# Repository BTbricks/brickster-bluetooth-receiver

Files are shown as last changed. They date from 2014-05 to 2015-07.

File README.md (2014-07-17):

# BricksTer &ndash; Bluetooth Receiver

BricksTer Bluetooth Receiver top side&nbsp;&nbsp;&nbsp;BricksTer Bluetooth Receiver bottom side

The BricksTer Bluetooth Receiver lets you wirelessly control your LEGO creations from a smart phone, tablet, or PC. It is compatible with the NXT programmable brick. This repository houses the Eagle CAD schematic and design files for the printed circuit board along with the firmware for the receiver.

## Getting Started

### Part List

Components can be ordered from any distributor (e.g. DigiKey, Mouser, etc).  
[Please see the Bill of Materials for the list of components.](https://github.com/BTbricks/brickster-bluetooth-receiver/blob/master/8884bt%20Remote%20Control%20Receiver/board/BOM.md)

The rev. 2 board can be purchased from OSH Park.  
[Click here to view the OSH Park project page.](https://oshpark.com/shared_projects/jNrizzs2)

### Programming the Board

Once your board is soldered, use the Arduino IDE to load the firmware onto the microcontroller.  
The IDE is available for free and can be downloaded from http://arduino.cc/main/software

#### Setting up the Arduino Environment

The microcontroller is an ATtiny84, which is not regularly supported by the Arduino IDE.  
[Please visit the Arduino support page to learn more about using Arduino with the ATtiny84.](http://playground.arduino.cc/Main/ArduinoOnOtherAtmelChips)

Download the [Attiny 44/45/84/85 files](https://github.com/damellis/attiny/archive/master.zip) and extract them to `{ARDUINO}/hardware/`, where `{ARDUINO}` represents the directory into which the Arduino IDE and supporting files have been installed. Once completed, your directory should look like this:

```
{ARDUINO}
└-hardware
  └-attiny
    ├-boards.txt
    └-variants
      ├-tiny8
      | └-pins_arduino.h
      └-tiny14
        └-pins_arduino.h
```

#### Burning the "Bootloader"

The ATtiny84 comes from the factory running on an internal 1 MHz clock. In order to run the BricksTer firmware, the ATtiny84 must be told to use its interal 8 MHz clock.

* Connect your board to your computer via the programmer
* Apply power to the power-in Power Functions wire
* Open the Arduino IDE
* Ensure you have selected the proper serial port (`Tools > Serial Port`) and can communicate with the microcontroller
* Select `Tools > Board > ATtiny84 (internal 8 Mhz clock)`
* Select `Tools > Burn Bootloader`
* Wait for the programmer to finish, the IDE should display a success message

#### Loading the Firmware

* Connect your board to your computer via the programmer
* Apply power to the power-in Power Functions wire
* Open the Arduino IDE
* Ensure you have selected the proper serial port (`Tools > Serial Port`) and can communicate with the microcontroller
* Select `Tools > Board > ATtiny84 (internal 8 Mhz clock)`
* Open the firmware file, [`brickster8884bt.ino`](https://github.com/BTbricks/brickster-bluetooth-receiver/blob/master/8884bt%20Remote%20Control%20Receiver/firmware/brickster8884bt.ino)
* Click the Upload button on the Arduino IDE (circle with a right-pointing arrow)
* Wait for the the IDE and programmer to finish, the IDE should display a success message

Note: Use of a Atmel AVRISPmk2 programmer is strongly advised. Other programmers have been known to work, but we can only provide support for the AVRISPmk2.

### File Formats

Design files are created in CadSoft Eagle PCB Design Software.  
A free version of the software can be downloaded from www.cadsoftusa.com

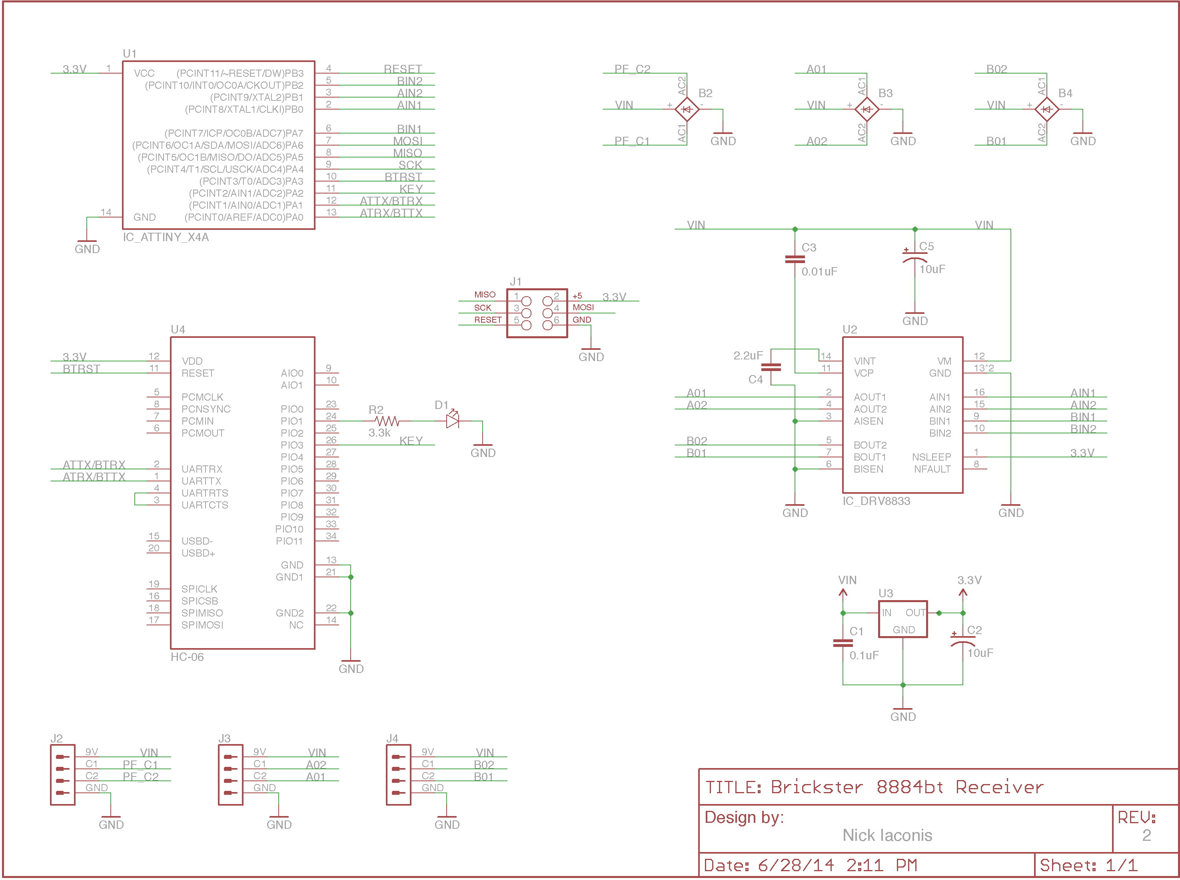
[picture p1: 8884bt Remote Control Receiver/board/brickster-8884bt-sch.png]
BricksTer Bluetooth Receiver schematic
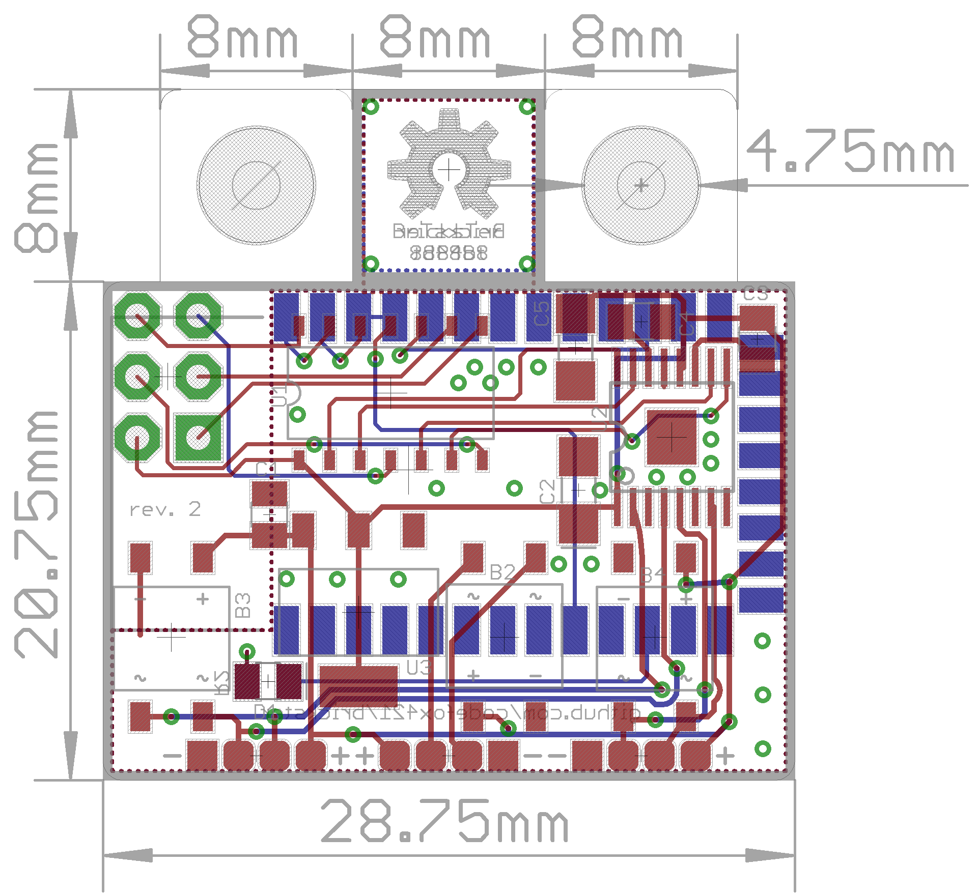
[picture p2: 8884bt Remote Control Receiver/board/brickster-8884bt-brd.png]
BricksTer Bluetooth Receiver board design
&nbsp;&nbsp;&nbsp;

## Distribution License

Where possible, this project uses the MIT license. [Please see the license file for full details.](https://github.com/BTbricks/brickster-bluetooth-receiver/blob/master/LICENSE)

## Contributing

The project is open to all issues and pull requests.  
If you have any other questions or feedback, please [contact the project maintainers](https://github.com/orgs/BTbricks/members).

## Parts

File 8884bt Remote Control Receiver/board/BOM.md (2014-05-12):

# Bill of Materials

Listed here is a complete bill of materials for assembling one bluetooth receiver.

## Example listing

+ **Identifier** Device Package (ManufacturerPartNumber) _comment_

## 8884bt Bluetooth Receiver

+ **U1** ATtiny84 SOIC14 (ATTINY84-20SSUR)
+ **U2** MotorDriver SOP16 (DRV8833PWPR)
+ **U3** Regulator3.3V SOT223 (NCP1117ST33T3G)
+ **U4** BluetoothModule SMD34 (HC-06)

+ **B2/B3/B4** BridgeRectifier MBS-2 (CDBHM240L-HF)

+ **D1** BlueLED 0805 (150080BS75000)

+ **C1** CapCer0.1uF 0805 (CC0805ZRY5V9BB104)
+ **C2/C5** CapCer10uF 1206 (CL31F106ZOHNNNE)
+ **C3** CapCer10000pF 0805 (CC0805KRX7R9BB103)
+ **C4** CapCer2.2uF 0805 (CL21F225ZOFNNNE)

+ **R2** Res3.3kOhm 0805 (RMCF0805JT3K30)

+ **J1** ProgrammerICSP N/A (N/A) _used to program the ATtiny84, use of pogo pins is advised, no external power!_
+ **J2/J3/J4** WirePF N/A ([8886](http://shop.lego.com/en-US/LEGO-Power-Functions-Extension-Wire-8886 "Power Functions Extension Wire") _or_ [8871](http://shop.lego.com/en-US/LEGO-Power-Functions-Extension-Wire-20-8871 "Power Functions Extension Wire 20"")) _octagon pads denote 9V, square pads denote GND_

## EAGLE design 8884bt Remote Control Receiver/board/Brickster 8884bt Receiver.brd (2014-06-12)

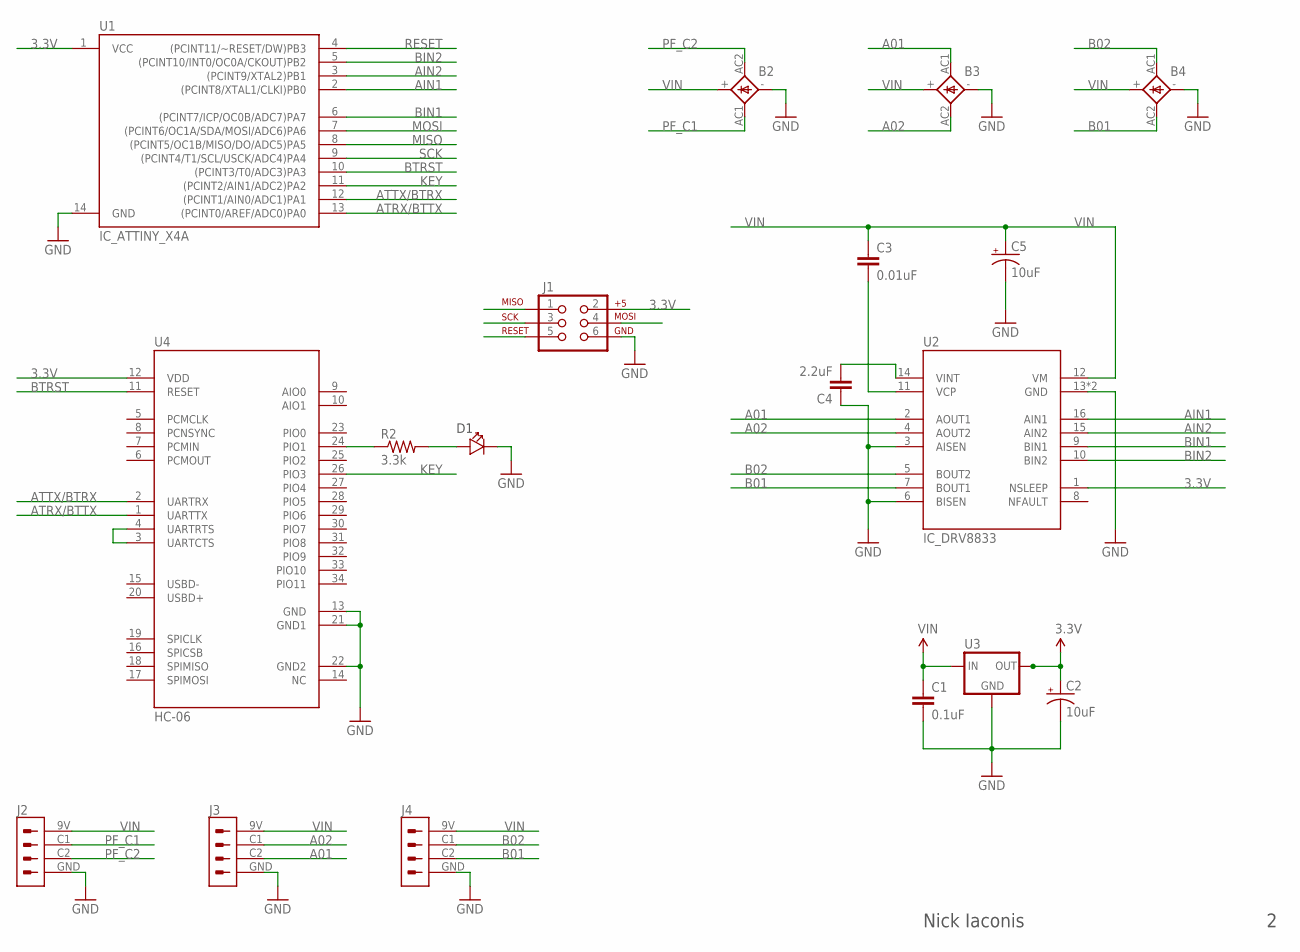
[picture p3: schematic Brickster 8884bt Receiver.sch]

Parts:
B2, B3, B4: B_CDBHM240L-HF; MBS-2
C1: 0.1uF; 0805
C2, C5: 10uF; 1206
C3: 0.01uF; 0805
C4: 2.2uF; 0805
D1: LED0805; 0805_POL
J1: AVR_SPI_PRG_6NS; 2X3-NS
J2, J3, J4: CON_PF_SMD; SMD_PF
R2: 3.3k; 0805
U1: IC_ATTINY_X4A; 14S1
U2: IC_DRV8833; PWP_R-PDSO-G16
U3: IC_RT9164A; SOT223
U4: HC-06; BLUETOOTH_SMD

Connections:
3.3V: C2.1 (+), J1.2, U1.1 (VCC), U2.1 (NSLEEP), U3.2 (OUT), U3.4, U4.12 (VDD)
A01: B3.AC1, J3.C2, U2.2 (AOUT1)
A02: B3.AC2, J3.C1, U2.4 (AOUT2)
AIN1: U1.2 ((PCINT8/XTAL1/CLKI)PB0), U2.16 (AIN1)
AIN2: U1.3 ((PCINT9/XTAL2)PB1), U2.15 (AIN2)
ATRX/BTTX: U1.13 ((PCINT0/AREF/ADC0)PA0), U4.1 (UARTTX)
ATTX/BTRX: U1.12 ((PCINT1/AIN0/ADC1)PA1), U4.2 (UARTRX)
B01: B4.AC2, J4.C2, U2.7 (BOUT1)
B02: B4.AC1, J4.C1, U2.5 (BOUT2)
BIN1: U1.6 ((PCINT7/ICP/OC0B/ADC7)PA7), U2.9 (BIN1)
BIN2: U1.5 ((PCINT10/INT0/OC0A/CKOUT)PB2), U2.10 (BIN2)
BTRST: U1.10 ((PCINT3/T0/ADC3)PA3), U4.11 (RESET)
GND: B2.-, B3.-, B4.-, C1.P$2 (2), C2.2 (-), C4.P$1 (1), C5.2 (-), D1.P$1, J1.6, J2.GND, J3.GND, J4.GND, U1.14 (GND), U2.3 (AISEN), U2.6 (BISEN), U2.13 (GND), U2.17 (GND), U3.1 (GND), U4.13 (GND), U4.21 (GND1), U4.22 (GND2)
KEY: U1.11 ((PCINT2/AIN1/ADC2)PA2), U4.26 (PIO3)
LED: R2.P$1 (1), U4.24 (PIO1)
MISO: J1.1, U1.8 ((PCINT5/OC1B/MISO/DO/ADC5)PA5)
MOSI: J1.4, U1.7 ((PCINT6/OC1A/SDA/MOSI/ADC6)PA6)
unnamed: C3.P$2 (2), U2.11 (VCP)
unnamed: C4.P$2 (2), U2.14 (VINT)
unnamed: U4.3 (UARTCTS), U4.4 (UARTRTS)
unnamed: D1.P$2, R2.P$2 (2)
PF_C1: B2.AC1, J2.C1
PF_C2: B2.AC2, J2.C2
RESET: J1.5, U1.4 ((PCINT11/~RESET/DW)PB3)
SCK: J1.3, U1.9 ((PCINT4/T1/SCL/USCK/ADC4)PA4)
VIN: B2.+, B3.+, B4.+, C1.P$1 (1), C3.P$1 (1), C5.1 (+), J2.9V, J3.9V, J4.9V, U2.12 (VM), U3.3 (IN)

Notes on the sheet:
Nick Iaconis

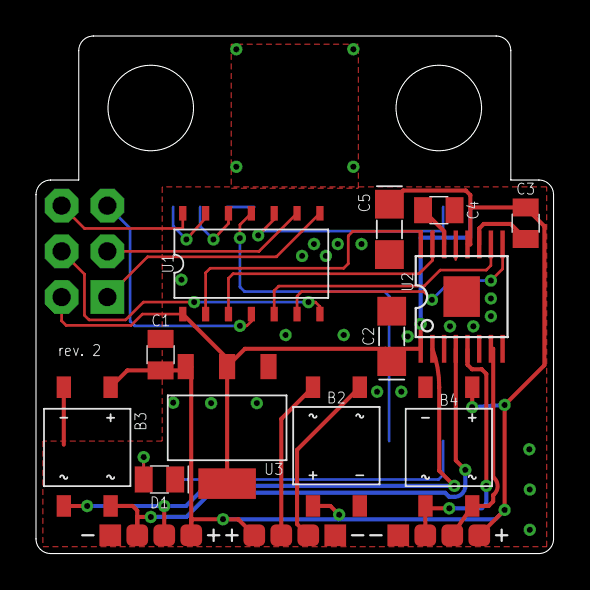
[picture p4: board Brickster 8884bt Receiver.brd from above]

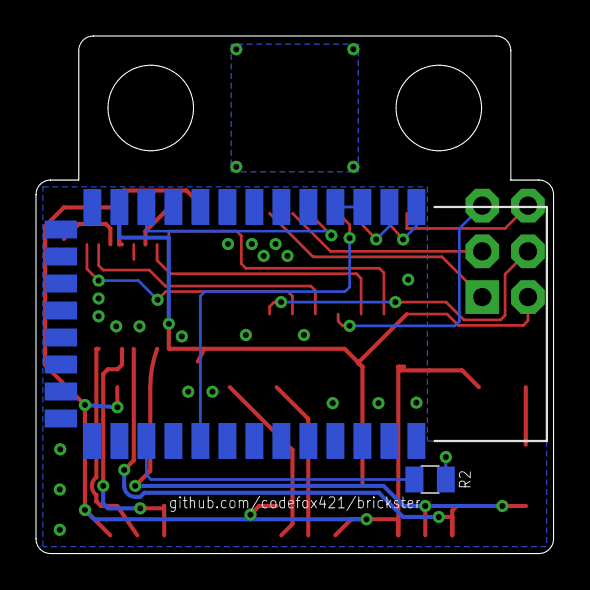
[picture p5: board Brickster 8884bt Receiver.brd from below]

Board: 2 copper layers, 28.8 x 28.8 mm, 20 parts (3 on the bottom side), 26 nets.

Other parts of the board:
LOGO1, LOGO2: OSHW-LOGOM; OSHW-LOGO-M-MASK

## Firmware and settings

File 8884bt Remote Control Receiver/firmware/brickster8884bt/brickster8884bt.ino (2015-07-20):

/*------------------------------------------------------------------------------
  The MIT License (MIT)

  Copyright (c) 2013 Nick Iaconis et al.
  
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
  THE SYSTEM IS PROVIDED "AS IS", WITHOUT WARRANTY OF ANY KIND, EXPRESS OR
  IMPLIED, INCLUDING BUT NOT LIMITED TO THE WARRANTIES OF MERCHANTABILITY,
  FITNESS FOR A PARTICULAR PURPOSE AND NONINFRINGEMENT. IN NO EVENT SHALL THE
  AUTHORS OR COPYRIGHT HOLDERS BE LIABLE FOR ANY CLAIM, DAMAGES OR OTHER
  LIABILITY, WHETHER IN AN ACTION OF CONTRACT, TORT OR OTHERWISE, ARISING FROM,
  OUT OF OR IN CONNECTION WITH THE SYSTEM OR THE USE OR OTHER DEALINGS IN THE
  SYSTEM.
------------------------------------------------------------------------------*/

/*------------------
  #### ATtiny84 ####
  ------------------
         ____       
  VCC  <|*   |> GND 
  IO10 <|    |> IO 0
  IO 9 <|    |> IO 1
  RST  <|    |> IO 2
  IO 8 <|    |> IO 3
  IO 7 <|    |> SCK 
  MOSI <|____|> MISO

  ------------------*/

/*----------------------------
  #### Swap Motor Drivers ####
  ----------------------------
  
  Regex:   ^( *)(.*tb6612fng)
  Replace: $1//$2
  
  Regex:   ^( *)//(.*drv8833)
  Replace: $1$2
  
  ----------------------------*/

#include <SoftwareSerial.h>
#define uSecCyc 870

// Motor control A
//#define mcPin1A 1 // tb6612fng
//#define mcPin2A 2 // tb6612fng
//#define pwmPinA 3 // tb6612fng
#define mcPin1A 10 // drv8833
#define mcPin2A 9 // drv8833
char pwmPinA = mcPin1A; // drv8833
#define maxA 28
char levelA = 0;
int pwmA = 0;

// Motor control B
//#define mcPin1B 0 // tb6612fng
//#define mcPin2B 8 // tb6612fng
//#define pwmPinB 7 // tb6612fng
#define mcPin1B 7 // drv8833
#define mcPin2B 8 // drv8833
char pwmPinB = mcPin1B; // drv8833
#define maxB 28
char levelB = 0;
int pwmB = 0;

// Channel A commands
#define maskA 83
#define upA 65    // A up         = A
#define downA 66  // A down       = B
#define brakeA 67 // A brake      = C
#define floatA 80 // A float      = P
#define ffwdA 81  // A full fwd   = Q
#define frevA 82  // A full rev   = R

// Channel B commands
#define maskB 108
#define upB 68    // B up         = D
#define downB 72  // B down       = H
#define brakeB 76 // B brake      = L
#define floatB 96 // B float      = `
#define ffwdB 100 // B full fwd   = d
#define frevB 104 // B full rev   = h

// Combine Channel A command with Channel B command using logical OR

// Software serial
//#define rxPin 10 // tb6612fng
//#define txPin 9 // tb6612fng
#define rxPin 0 // drv8833
#define txPin 1 // drv8833
#define baudRate 9600
SoftwareSerial softSerial(rxPin, txPin);

// Miscellanious
#define btResetPin 3
char incomingByte = 0;
char maskedByte = 0;
char serialRateLimiter = 0;
// int pwmLevels[8] = {0, 218, 326, 435, 544, 653, 761, 870};
int pwmLevels[29] = {0, 141, 168, 195, 222, 249, 276, 303, \
                      330, 357, 384, 411, 438, 465, 492, \
                      519, 546, 573, 600, 627, 654, 681, \
                      708, 735, 762, 789, 816, 843, 870};

// Function definitions
void comboMode(const char, char*, const char, const char, \
                const char, const char, const char, const char, \
                const char, const char, const char, const char);
void bitBangPwm(char, int, char, int);



/*----------------------------------------------------------------------------*/



void setup()
{
  // bluetooth control init
  pinMode(btResetPin, OUTPUT);
  digitalWrite(btResetPin, HIGH); // end Bluetooth reset (enable module)
  
  // channel A init
  pinMode(mcPin1A, OUTPUT);
  pinMode(mcPin2A, OUTPUT);
  pinMode(pwmPinA, OUTPUT);
  digitalWrite(mcPin1A, LOW);
  digitalWrite(mcPin2A, LOW);
  digitalWrite(pwmPinA, LOW);
  
  // channel B init
  pinMode(mcPin1B, OUTPUT);
  pinMode(mcPin2B, OUTPUT);
  pinMode(pwmPinB, OUTPUT);
  digitalWrite(mcPin1B, LOW);
  digitalWrite(mcPin2B, LOW);
  digitalWrite(pwmPinB, LOW);
  
  // bitbanged PWM init
  pwmA = pwmLevels[min(abs(levelA), maxA)];
  pwmB = pwmLevels[min(abs(levelB), maxB)];
  
  // serial init
  softSerial.begin(baudRate);
}



void loop()
{
  // Handle serial communication
  //   - software serial interferes with PWM
  //   - limit to once every 8(?) loops
  if (!serialRateLimiter && softSerial.available() > 0)
  {
    // read incoming byte
    incomingByte = softSerial.read();
    

    // Direct PWM mode (fine resolution)
    if (incomingByte & 128) // 1xxx xxxx
    {
      // select proper output
      char* levelX = incomingByte & 64 ? &levelB : &levelA;
      if ((incomingByte & 63) < 29 || (incomingByte & 63) > 35)
      {
        // set the level
        *levelX = (incomingByte & 31) | (incomingByte & 32 ? 224 : 0);
        // set the motor control wires
        digitalWrite(incomingByte & 64 ? mcPin1B : mcPin1A, (*levelX > 0 ? HIGH : LOW));
        digitalWrite(incomingByte & 64 ? mcPin2B : mcPin2A, (*levelX < 0 ? HIGH : LOW));
      }
      else if ((incomingByte & 63) == 32) // xx10 0000 -> brake
      {
        // set the level
        *levelX = 0;
        // set the motor control wires
        digitalWrite(incomingByte & 64 ? mcPin1B : mcPin1A, HIGH);
        digitalWrite(incomingByte & 64 ? mcPin2B : mcPin2A, HIGH);
      }
      // notify sender
      softSerial.write(*levelX);
    }

    // Combo output mode
    else if (incomingByte & 64) // 01xx xxxx
    {
      // set channel A
      comboMode(incomingByte, &levelA, maxA, maskA, brakeA, floatA, \
                  upA, downA, ffwdA, frevA, mcPin1A, mcPin2A);
      // set channel B
      comboMode(incomingByte, &levelB, maxB, maskB, brakeB, floatB, \
                  upB, downB, ffwdB, frevB, mcPin1B, mcPin2B);
      // notify sender
      maskedByte = abs(levelB >> 2) + (levelB < 0 ? 8 : 0);
      maskedByte = (maskedByte << 4) + abs(levelA >> 2) + (levelA < 0 ? 8 : 0);
      softSerial.write(maskedByte);
    }
    
    // set the pwm
    pwmA = pwmLevels[min(abs(levelA), maxA)];
    pwmPinA = levelA < 0 ? mcPin2A : mcPin1A; // drv8833
    pwmB = pwmLevels[min(abs(levelB), maxB)];
    pwmPinB = levelB < 0 ? mcPin2B : mcPin1B; // drv8833
    
    // rate limit
    serialRateLimiter = 8;
  }
  
  // Bitbang the PWM signals
  bitBangPwm(pwmPinA, pwmA, pwmPinB, pwmB);
  
  // Decrement rate limiter
  if (serialRateLimiter)
    --serialRateLimiter;
  
}



/*----------------------------------------------------------------------------*/




void comboMode(const char incomingByte, char* levelX, const char maxX, \
                const char maskX, const char brakeX, const char floatX, \
                const char upX, const char downX, const char ffwdX, \
                const char frevX, const char mcPin1X, const char mcPin2X)
{
  maskedByte = incomingByte & maskX;
  // decode command
  if (maskedByte == brakeX || maskedByte == floatX)
  {
    *levelX = 0;
  }
  else if (maskedByte == upX)
  {
    if (*levelX >= 0)
    {
      *levelX = min((*levelX + 4) & ~3, maxX);
    }
    else
    {
      if (abs(*levelX) & 3)
        *levelX = -(abs(*levelX) & ~3);
      else
        *levelX += 4;
    }
  }
  else if (maskedByte == downX)
  {
    if (*levelX <= 0)
    {
      *levelX = -min((abs(*levelX) + 4) & ~3, maxX);
    }
    else
    {
      if (*levelX & 3)
        *levelX &= ~3;
      else
        *levelX -= 4;
    }
  }
  else if (maskedByte == ffwdX)
  {
    *levelX = maxX;
  }
  else if (maskedByte == frevX)
  {
    *levelX = -maxX;
  }

  // set the motor control wires
  digitalWrite(mcPin1X, (*levelX > 0 || maskedByte == brakeX ? HIGH : LOW));
  digitalWrite(mcPin2X, (*levelX < 0 || maskedByte == brakeX ? HIGH : LOW));
}



void bitBangPwm(char thePwmPinA, int pwmA, char thePwmPinB, int pwmB)
{
  // Bitbang the PWM signals
  // turn on both channels
  if (pwmA > 0)
    digitalWrite(thePwmPinA, HIGH);
  if (pwmB > 0)
    digitalWrite(thePwmPinB, HIGH);
  if (pwmA <= pwmB)
  {
    // pwmA is shorter
    if (pwmA > 0)
    {
      delayMicroseconds(pwmA);
      // channelA off
      digitalWrite(thePwmPinA, LOW);
    }
    // wait the difference
    if (pwmA != pwmB)
    {
      delayMicroseconds(pwmB - pwmA);
    }
    if (pwmB > 0)
    {
      // channelB off
      digitalWrite(thePwmPinB, LOW);
    }
    // finish out the cycle
    if (pwmB < uSecCyc)
      delayMicroseconds(uSecCyc - pwmB);
  }
  else
  {
    // pwmB is shorter
    if (pwmB > 0)
    {
      delayMicroseconds(pwmB);
      // channelB off
      digitalWrite(thePwmPinB, LOW);
    }
    // wait the difference
    if (pwmA != pwmB)
    {
      delayMicroseconds(pwmA - pwmB);
    }
    if (pwmA > 0)
    {
      // channelA off
      digitalWrite(thePwmPinA, LOW);
    }
    // finish out the cycle
    if (pwmA < uSecCyc)
      delayMicroseconds(uSecCyc - pwmA);
  }
}

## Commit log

2014-02-27 Clear bluetooth-receiver history in order to merge with android into master
    [Brickster 8884bt Receiver.brd, Brickster 8884bt Receiver.sch]
2014-03-20 Update receiver to revision 1a
    [Brickster 8884bt Receiver.brd, Brickster 8884bt Receiver.sch]
2014-03-20 Update board & schematic images
2014-04-10 Implement command architecture described at http://codepen.io/anon/pen/nxhzt/ Prepare firmware for switch to drv8833 motor driver chip
2014-04-28 Add drv8833 to library and schematic
    [Brickster 8884bt Receiver.brd, Brickster 8884bt Receiver.sch]
2014-05-12 Route rev. 2 board
    Need to change OSH logo to t/b-stop
    [Brickster 8884bt Receiver.brd, Brickster 8884bt Receiver.sch]
2014-05-12 Change regulator manufacturer
2014-06-12 Route rev. 2 board
    Use SMD pads for Power Functions connections
    (threading PF wire through tiny vias is too difficult)
    [Brickster 8884bt Receiver.brd, Brickster 8884bt Receiver.sch]
2014-06-29 Update firmware for rev. 2 board
2014-06-29 Update schematic/board PNGs
2014-06-29 Uncomment missing lines necessary for rev. 2
    [brickster8884bt.ino]
2014-08-11 Fix bug when braking with drv8833
    [brickster8884bt.ino]
2014-08-21 Use default 9600 baud rate
    The baud rate of 57600 was causing some stability issues. The ATtiny84's
    internal oscillator is too sensitive to the environment (mostly
    temperature) to use such a high rate. The default of 9600 should be just
    fine now that only one single byte is being sent for every byte
    received.
    [brickster8884bt.ino]
2014-08-21 Don't restart the Bluetooth module at boot
    Since we aren't changing the baud rate, we no longer need to reset the
    Bluetooth module at boot
    [brickster8884bt.ino]
2015-07-20 Move ino file into a sketch directory
    This will allow Arduino IDE to open it in place.
2015-07-20 Ensure Bluetooth module is enabled on boot
    Without explicitly writing HIGH to the !BTRST line, the module could be
    in reset mode.
    [brickster8884bt.ino]

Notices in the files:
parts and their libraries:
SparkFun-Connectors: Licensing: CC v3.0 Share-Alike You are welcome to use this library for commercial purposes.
